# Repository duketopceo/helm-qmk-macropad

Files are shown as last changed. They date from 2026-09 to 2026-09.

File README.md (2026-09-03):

# Helm

Private. Made-to-order USB-C macropad. Developer-first command surface, QMK/Vial second, real Linux (Omarchy/Hyprland) as the wedge Elgato and Logitech skip.

**First working build:** 6 MX keys (2×3) + one clickable aluminum EC11 knob. Hand-soldered. Seeed XIAO RP2040. PETG two-piece, 15° desk wedge. No custom app until it enumerates as HID on macOS, Windows, and Linux.

## Locked spec

| | |
|---|---|
| Layout | 6× MX 2×3 + 1× EC11 click-knob |
| Angle | **15°** wedge, front low, USB at the tall rear. Not Stream Deck Mini's 45° (that's for LCDs) |
| Keys | **PCB-mount / 5-pin** MX. Plate is **1.5 mm** at the clips (Cherry spec; thicker and they do not latch) |
| Knob | **Threaded** EC11 + nut + washer. Body sits on a printed shelf. No snap-in-only encoder |
| MCU | Seeed XIAO RP2040, USB-C rear, wired. Cable zip-tied at the rear wall |
| Firmware v1 | QMK + Vial (`vial.rocks`). Prebuilt: `firmware/handwired_helm_vial.uf2` |
| Case | Dark PETG, 2.4 mm walls, 4× M2 heat-set inserts, 2 alignment pins. No structural snaps |
| Out of v1 | ESP32, RGB, screen, wireless, 5 knobs, companion app, Stripe |

MX cutout 14.0 mm @ 19.05 mm pitch, 0.5 mm corner radii, 1.8 mm holes at ±5.08 mm for the plastic legs. EC11 bushing 7.2 mm. XIAO pocket 21.2×17.7×1.2 mm. Plate ~75×65 mm in the key plane; desk footprint ~75×62 mm. Rear wall ~26 mm tall.

USB-C on the XIAO is reversible (plug either flip). The board only faces rear.

## First-working sequence

1. Flying-lead **one key + one encoder**, flash Vial, confirm HID on all three OSes.
2. Print the 15° shell + 1.5 mm plate.
3. Seat 5-pin MX, nut the encoder, zip-tie the USB cable, solder the other five keys, close with M2.
4. Daily-drive a week. If the knob is only volume, we keep one knob forever.

## Buy list (v1)

See `BOM.md`. Short version: XIAO ×2, **5-pin** Gateron MX 10-pack, **threaded** EC11 + nut + washer + aluminum knob, 6× 1u PBT blanks, M2 inserts + M2×8–10 screws, zip-tie, 26–28 AWG, PETG you already have.

## Competition (why not 5 knobs)

- Stream Deck Mini — 6 keys, 45° LCD stand, still the compact one people love
- Stream Deck + — 8 LCD + 4 dials; 4 knobs is the ceiling
- Logitech MX Creative Console — 9 LCD + **one** big dial
- OpenAI Codex Micro / Work Louder Creator Micro 2 — 13 keys + **one** reasoning dial, $230

Helm's gap: cheap QMK MX + one knob + Linux that actually works. Free 3×3 Arduino STLs (e.g. SNASA on Printables) are the hobby floor, NC-licensed, and not this product.

## Repo layout

```
├── cad/             # Parametric OpenSCAD (edit helm_parameters.scad)
│   ├── helm_parameters.scad
│   ├── helm_plate.scad
│   └── helm_bottom.scad
├── stl/             # Generated plate and bottom
├── firmware/
│   ├── handwired_helm_vial.uf2
│   └── qmk/keyboards/handwired/helm/
├── WIRING.md
└── BOM.md
```

## How to print (Ender V3, PETG)

1. Slice `stl/helm_plate.stl` and `stl/helm_bottom.stl`.
2. **Plate:** flat on the bed, switch-face up. **100% infill, ≥4 walls**, 0.15–0.20 mm layers. No supports. Do not thicken the plate past 1.6 mm or MX clips will not lock.
3. **Bottom:** desk-face on the bed (USB slot in the tall rear wall, bosses up). No supports. 4 walls, 25–30% infill is fine.
4. ~240 °C PETG / 80 °C bed, 45 mm/s outer walls.
5. Rebuild STLs after CAD edits (run from `cad/` so the include resolves):

```bash
cd cad
openscad -o ../stl/helm_plate.stl helm_plate.scad
openscad -o ../stl/helm_bottom.stl helm_bottom.scad
```

6. Heat-set four M2 inserts from the **plate side** of the bosses (~200 °C iron, vertical, no twisting). Alignment pins locate the plate. M2 screws, not snaps.

Hold XIAO **BOOT while plugging USB** to flash. There are no underside button holes.

## How to flash

Fast path: hold BOOT, plug USB, copy `firmware/handwired_helm_vial.uf2` onto the `RPI-RP2` drive.

Rebuild:

1. Clone `vial-kb/vial-qmk` and run `qmk setup` against it.
2. Copy `firmware/qmk/keyboards/handwired/helm/` into `keyboards/handwired/`.
3. `qmk compile -kb handwired/helm -km vial`
4. Same UF2 copy as above.

## Verify HID

- **macOS** — System Settings > Keyboard should list "Helm". The first key emits `KC_MUTE`.
- **Windows** — HID Keyboard, VID `0x484D` PID `0x0001`.
- **Omarchy / Hyprland** — `lsusb` / `dmesg`. Open `vial.rocks`, authorize, test all 6 keys, knob click, and both rotate directions.

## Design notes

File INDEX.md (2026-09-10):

# INDEX.md — Luke Grounding Index

> **Index version:** `v2.0.0`
> **Repo version:** `1.0.0`
> **Last synced:** `2026-09-10T07:20:22.933510+00:00`
> **Schema:** `Path | Version | Last updated | What it is | Why it's here | Depends on`
>
> **This file is auto-generated by `scripts/luke-index-watcher.py`.**
> Hand-maintained `What it is`, `Why it's here`, and `Depends on` values are preserved.

---

## 1. Security & Leak Risk

> [!IMPORTANT]
> Run `python scripts/luke-index-watcher.py` after any non-trivial repo change to keep this index current.
> Never commit live keys, tokens, or PII. See `GUARDRAILS.md` §6 and `SECURITY_GUIDELINES.md`.

---

## 2. Root-level files

| Path | Version | Last updated | What it is | Why it's here | Depends on |
| --- | --- | --- | --- | --- | --- |
| BOM.md | 1.0.0 | 2026-09-03T05:07:35 |  |  |  |
| INDEX.md | 1.0.0 | 1970-01-01T00:00 |  |  |  |
| README.md | 1.0.0 | 2026-09-03T05:07:35 |  |  |  |
| WIRING.md | 1.0.0 | 2026-09-03T05:07:35 |  |  |  |

## 3. `cad/`

| Path | Version | Last updated | What it is | Why it's here | Depends on |
| --- | --- | --- | --- | --- | --- |
| cad/helm_bottom.scad | 1.0.0 | 2026-09-03T04:55:53 |  |  |  |
| cad/helm_parameters.scad | 1.0.0 | 2026-09-03T04:55:53 |  |  |  |
| cad/helm_plate.scad | 1.0.0 | 2026-09-03T04:55:53 |  |  |  |
| cad/preview.png | 1.0.0 | 2026-09-03T04:55:53 |  |  |  |
| cad/preview_bottom.png | 1.0.0 | 2026-09-03T04:55:53 |  |  |  |
| cad/preview_plate.png | 1.0.0 | 2026-09-03T04:55:53 |  |  |  |

## 3. `firmware/`

| Path | Version | Last updated | What it is | Why it's here | Depends on |
| --- | --- | --- | --- | --- | --- |
| firmware/handwired_helm_vial.uf2 | 1.0.0 | 2026-09-03T04:06:47 |  |  |  |
| firmware/qmk/keyboards/handwired/helm/config.h | 1.0.0 | 2026-09-03T04:06:47 |  |  |  |
| firmware/qmk/keyboards/handwired/helm/keyboard.json | 1.0.0 | 2026-09-03T04:06:47 |  |  |  |
| firmware/qmk/keyboards/handwired/helm/keymaps/vial/keymap.c | 1.0.0 | 2026-09-03T04:06:47 |  |  |  |
| firmware/qmk/keyboards/handwired/helm/keymaps/vial/rules.mk | 1.0.0 | 2026-09-03T04:00:24 |  |  |  |
| firmware/qmk/keyboards/handwired/helm/keymaps/vial/vial.json | 1.0.0 | 2026-09-03T04:00:24 |  |  |  |
| firmware/qmk/keyboards/handwired/helm/rules.mk | 1.0.0 | 2026-09-03T04:00:24 |  |  |  |

## 3. `scripts/`

| Path | Version | Last updated | What it is | Why it's here | Depends on |
| --- | --- | --- | --- | --- | --- |
| scripts/luke-index-watcher.py | 1.0.0 | 1970-01-01T00:00 |  |  |  |

## 3. `stl/`

| Path | Version | Last updated | What it is | Why it's here | Depends on |
| --- | --- | --- | --- | --- | --- |
| stl/helm_bottom.stl | 1.0.0 | 2026-09-03T04:55:53 |  |  |  |
| stl/helm_plate.stl | 1.0.0 | 2026-09-03T04:55:53 |  |  |  |

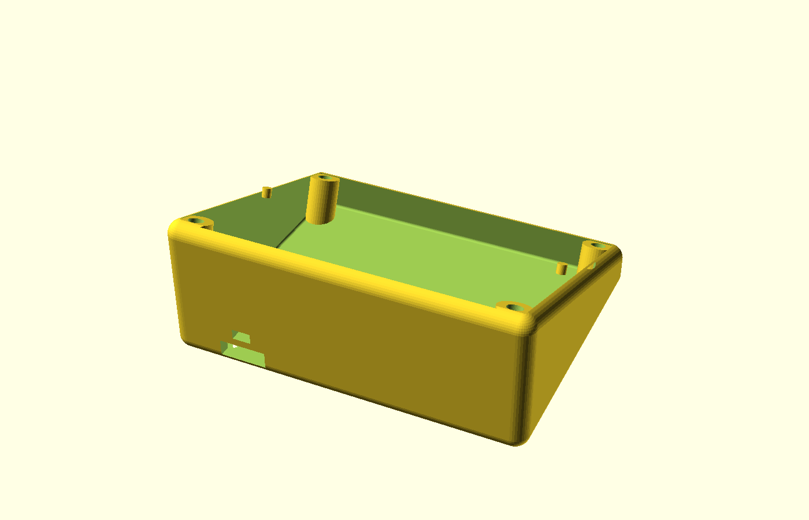
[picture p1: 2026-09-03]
cad/preview_bottom.png

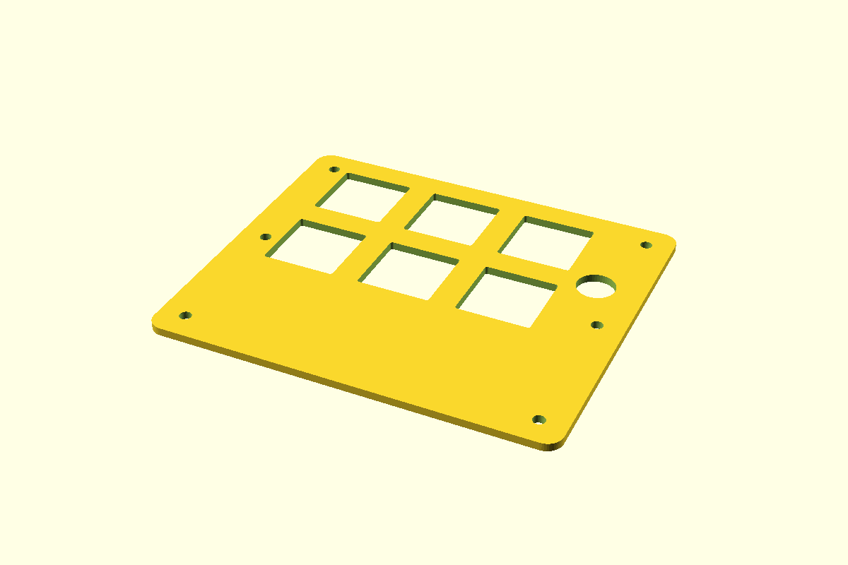
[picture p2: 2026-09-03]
cad/preview_plate.png

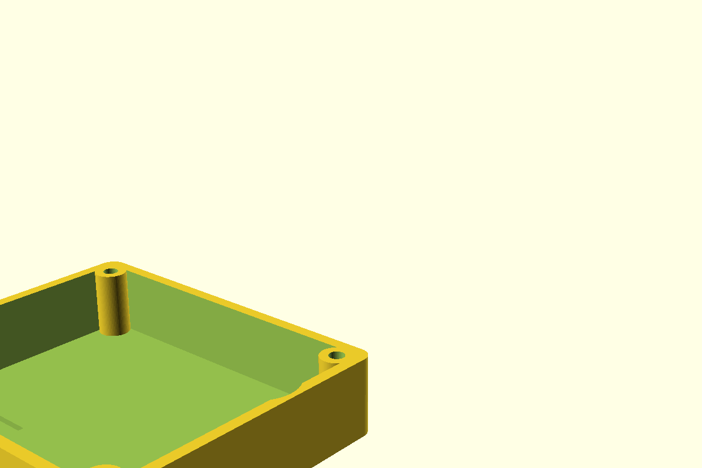
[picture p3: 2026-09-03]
cad/preview.png

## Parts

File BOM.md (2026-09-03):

# Helm v1 BOM

| Item | Qty | Notes |
|---|-----|---|
| Seeed Studio XIAO RP2040 | 2 | One for the build, one spare |
| Gateron (or Cherry) **PCB-mount 5-pin** MX | 6 | Buy a 10-pack. 3-pin plate-only switches skip the anti-rotation pegs |
| EC11 with **threaded bushing + nut + washer**, push switch | 1 | ~7 mm bushing. Skip Alps parts with no collar |
| Aluminum knob | 1 | 6 mm D-shaft |
| 1u PBT blank keycaps | 6 | MX stem |
| M2 brass heat-set inserts | 4 | Length 3–4 mm, OD ~3.5 mm. Iron ~200 °C in PETG |
| M2 pan-head screws | 4 | **8–10 mm** (insert + 1.5 mm plate) |
| Small nylon zip-tie | 1 | Strain relief through the rear-wall slot |
| 26–28 AWG stranded wire | ~2 m | Direct-pin flying leads |
| Dark PETG | ~50 g | Plate + bottom |
| Rubber feet | 4 | Optional, 10 mm, sit in the recesses |

## Optional but recommended

- USB-C **data** cable (charge-only will not enumerate). Plug is reversible.
- Flux and no-clean solder for the XIAO castellated pads
- Flush cutters for EC11 legs
- Spare M2 inserts in case one spins

Do not substitute a snap-in-only encoder or a uniform plate thicker than 1.6 mm.

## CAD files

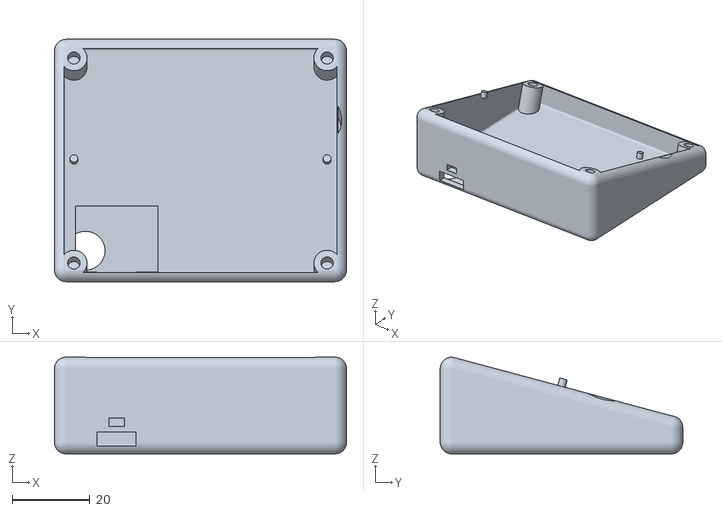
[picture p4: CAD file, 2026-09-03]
stl/helm_bottom.stl
75.1 x 62.4 x 24.9

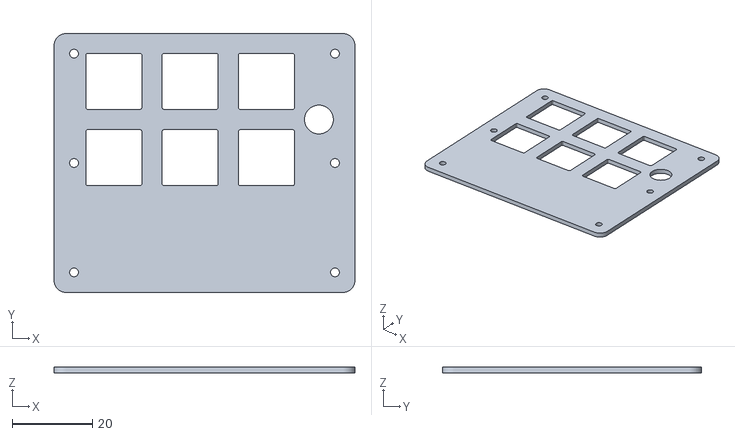
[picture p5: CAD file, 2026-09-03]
stl/helm_plate.stl
75.1 x 64.6 x 1.50

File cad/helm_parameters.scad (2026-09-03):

// Helm v1 — 6 MX (2x3) + 1 EC11 + XIAO RP2040
// Units: mm.
// y=0 rear (USB, tall). y=plate_depth front (toward the user, short).
// Key plane is desk_angle degrees off the desk. Front low, rear high.

// --- MX ---
mx_pitch     = 19.05;
mx_cutout    = 14.0;
mx_corner_r  = 0.5;   // stop PETG cracks at square hole corners
mx_peg_d      = 1.8;   // 5-pin plastic legs, KiCad ±5.08 mm from center
mx_peg_x      = 5.08;

// --- EC11 (buy the threaded-bushing version + nut + washer) ---
ec11_bushing = 7.2;
ec11_body    = 14.0;
bridge       = 2.5;

// --- case ---
wall             = 2.4;
corner_r         = 3.0;
plate_thickness  = 1.5;  // Cherry clip land; do not go thicker
case_floor       = 2.0;
front_h          = 9.0;   // wall height at the front lip (desk to plate underside)
desk_angle       = 15;
bay_gap          = 4.0;
align_pin_d      = 2.0;
align_pin_h      = 2.0;

// --- XIAO RP2040 ---
xiao_w            = 21.2;
xiao_d            = 17.7;
xiao_pocket_depth = 1.2;
usb_w             = 10.0;
usb_h             = 3.6;
usb_z             = case_floor;
zip_w             = 4.0;  // strain-relief zip-tie slot in the rear wall
zip_h             = 2.2;

// --- M2 heat-set ---
m2_through     = 2.2;
m2_insert      = 3.2;
m2_insert_h    = 4.5;
boss_d         = 6.8;
screw_inset    = 5.0;

// --- rubber feet ---
foot_d = 10.0;
foot_h = 0.8;
foot_inset = 8.0;

// --- derived layout (in the KEY / plate plane) ---
grid_x0 = wall + 3.0 + 0.5 * mx_pitch;
grid_y0 = wall + xiao_d + bay_gap + 0.5 * mx_pitch;

key_centers_x = [grid_x0, grid_x0 + mx_pitch, grid_x0 + 2 * mx_pitch];
key_centers_y = [grid_y0, grid_y0 + mx_pitch];

encoder_x = key_centers_x[2] + mx_cutout / 2 + bridge + ec11_bushing / 2;
encoder_y = (key_centers_y[0] + key_centers_y[1]) / 2;

plate_width = encoder_x + ec11_bushing / 2 + wall + 3.0;
plate_depth = key_centers_y[1] + 0.5 * mx_pitch + wall;

desk_depth = plate_depth * cos(desk_angle);
rear_h     = front_h + desk_depth * tan(desk_angle);

xiao_x = wall + 3.0;
xiao_y = wall;

screw_positions = [
    [screw_inset, screw_inset],
    [plate_width - screw_inset, screw_inset],
    [screw_inset, plate_depth - screw_inset],
    [plate_width - screw_inset, plate_depth - screw_inset]
];

// alignment pins sit mid-left and mid-right, in the key plane
align_positions = [
    [screw_inset, plate_depth / 2],
    [plate_width - screw_inset, plate_depth / 2]
];

foot_positions = [
    [foot_inset, foot_inset],
    [plate_width - foot_inset, foot_inset],
    [foot_inset, desk_depth - foot_inset],
    [plate_width - foot_inset, desk_depth - foot_inset]
];

function z_top(y_desk) = front_h + (desk_depth - y_desk) * tan(desk_angle);

module plate_to_world() {
    // plate coords: z up from plate underside, y from rear to front along the plate
    translate([0, 0, rear_h])
        rotate([-desk_angle, 0, 0])
            children();
}

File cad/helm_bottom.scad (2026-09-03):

include <helm_parameters.scad>
$fn = 40;

module wedge_solid(xy_inset) {
    r = max(0.4, corner_r - xy_inset);
    w = plate_width - 2 * xy_inset;
    d = desk_depth - 2 * xy_inset;
    hull() {
        for (x = [r, w - r], y = [r, d - r]) {
            translate([xy_inset + x, xy_inset + y, r])
                sphere(r = r);
            zt = z_top(xy_inset + y) - r;
            translate([xy_inset + x, xy_inset + y, zt])
                sphere(r = r);
        }
    }
}

module helm_bottom() {
    difference() {
        union() {
            difference() {
                wedge_solid(0);
                translate([0, 0, case_floor])
                    wedge_solid(wall);
            }

            // bosses stay inside the wedge
            intersection() {
                wedge_solid(0);
                union() {
                    for (p = screw_positions)
                        plate_to_world()
                            translate([p[0], p[1], -12])
                                cylinder(h = 12, d = boss_d);
                }
            }

            for (p = align_positions)
                plate_to_world()
                    translate([p[0], p[1], 0])
                        cylinder(h = align_pin_h, d = align_pin_d);
        }

        for (p = screw_positions)
            plate_to_world()
                translate([p[0], p[1], -m2_insert_h])
                    cylinder(h = m2_insert_h + 0.3, d = m2_insert);

        translate([xiao_x, xiao_y, case_floor - xiao_pocket_depth])
            cube([xiao_w, xiao_d * cos(desk_angle), xiao_pocket_depth + 0.2]);

        translate([xiao_x + xiao_w / 2 - usb_w / 2, -1, usb_z])
            cube([usb_w, wall + 2, usb_h]);

        translate([xiao_x + xiao_w / 2 - zip_w / 2, -1, usb_z + usb_h + 1.5])
            cube([zip_w, wall + 2, zip_h]);

        intersection() {
            translate([0, 0, case_floor + 0.5])
                cube([plate_width, desk_depth, rear_h]);
            plate_to_world()
                translate([encoder_x, encoder_y, -25])
                    cylinder(h = 25, d = ec11_body + 1.5);
        }

        for (p = foot_positions)
            translate([p[0], p[1], -0.01])
                cylinder(h = foot_h + 0.01, d = foot_d);
    }
}

helm_bottom();

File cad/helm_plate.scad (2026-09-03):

include <helm_parameters.scad>
$fn = 48;

module rounded_rect(w, d, r) {
    hull() {
        for (x = [r, w - r], y = [r, d - r])
            translate([x, y, 0]) circle(r = r);
    }
}

module mx_hole_2d() {
    offset(r = mx_corner_r)
        square(mx_cutout - 2 * mx_corner_r, center = true);
}

module helm_plate() {
    difference() {
        linear_extrude(height = plate_thickness)
            rounded_rect(plate_width, plate_depth, corner_r);

        for (x = key_centers_x, y = key_centers_y) {
            translate([x, y, -0.1])
                linear_extrude(height = plate_thickness + 0.2)
                    mx_hole_2d();
            // 5-pin plastic legs
            for (dx = [-mx_peg_x, mx_peg_x])
                translate([x + dx, y, -1])
                    cylinder(h = plate_thickness + 2, d = mx_peg_d);
        }

        translate([encoder_x, encoder_y, -1])
            cylinder(h = plate_thickness + 2, d = ec11_bushing);

        for (p = screw_positions)
            translate([p[0], p[1], -1])
                cylinder(h = plate_thickness + 2, d = m2_through);

        for (p = align_positions)
            translate([p[0], p[1], -1])
                cylinder(h = plate_thickness + 2, d = align_pin_d + 0.2);
    }
}

helm_plate();

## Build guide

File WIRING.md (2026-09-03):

# Helm wiring

Direct-pin: each switch terminal goes to one GPIO on the Seeed XIAO RP2040; the other terminal goes to GND. No matrix, no diodes. Pins match `firmware/qmk/keyboards/handwired/helm/keyboard.json`.

Looking at the plate, USB at the rear (away from you):

## Pin map

| Helm function | XIAO silk | RP2040 GPIO |
|---|---|---|
| Key 1 top left | D0 | GP26 |
| Key 2 top middle | D1 | GP27 |
| Key 3 top right | D2 | GP28 |
| Key 4 bottom left | D3 | GP29 |
| Key 5 bottom middle | D4 | GP6 |
| Key 6 bottom right | D5 | GP7 |
| EC11 click | D8 | GP2 |
| EC11 A | D9 | GP4 |
| EC11 B | D10 | GP3 |
| Ground rail | GND | — |

## Flying-lead first (1 key + 1 encoder)

1. Snap a **5-pin** MX into the plate (plastic legs into the 1.8 mm holes). Wire one terminal to **D0 (GP26)**, the other to **GND**.
2. Seat the EC11 from below. **Nut + washer on top of the plate.** Body rests on the printed shelf. A to **D9 (GP4)**, B to **D10 (GP3)**, click to **D8 (GP2)** and GND.
3. Drop the XIAO into the rear floor pocket, USB-C through the rear wall. Cable plugs either flip. **Zip-tie the cable in the slot above the USB hole** before you yank-test it.
4. Flash (`firmware/handwired_helm_vial.uf2` or rebuild). `vial.rocks`: one key, click, both rotate directions.

## Remaining 5 keys

Same as key 1: one terminal to D1 / D2 / D3 / D4 / D5, other to the GND rail. Tin the XIAO GND pad and fan a short rail. QMK enables RP2040 pull-ups; no extra resistors.

## Do not

- Mount the encoder on the 7.2 mm hole with no nut. Knob torque will crack the plate (Bento's failure mode).
- Skip the zip-tie. A USB yank pulls the XIAO out of the pocket.
- Rely on snaps to close the case. M2 inserts only.
- Expect underside BOOT holes. Hold **BOOT while plugging in**.

Keep D+/D- pads clear. Trim EC11 legs after soldering so the body clears the shelf.

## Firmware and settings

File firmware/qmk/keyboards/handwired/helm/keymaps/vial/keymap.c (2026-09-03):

#include QMK_KEYBOARD_H

const uint16_t PROGMEM keymaps[][MATRIX_ROWS][MATRIX_COLS] = {
    [0] = LAYOUT(
        KC_MUTE, KC_VOLU, KC_VOLD,
        KC_MPLY, KC_MNXT, KC_MPRV, KC_ENT
    ),
    [1] = LAYOUT(
        KC_1, KC_2, KC_3,
        KC_4, KC_5, KC_6, KC_0
    ),
    [2] = LAYOUT(
        KC_F1, KC_F2, KC_F3,
        KC_F4, KC_F5, KC_F6, KC_F7
    ),
    [3] = LAYOUT(
        KC_NO, KC_NO, KC_NO,
        KC_NO, KC_NO, KC_NO, KC_NO
    )
};

#if defined(ENCODER_MAP_ENABLE)
const uint16_t PROGMEM encoder_map[][NUM_ENCODERS][2] = {
    [0] = { ENCODER_CCW_CW(KC_VOLD, KC_VOLU) },
    [1] = { ENCODER_CCW_CW(KC_NO,   KC_NO)   },
    [2] = { ENCODER_CCW_CW(KC_NO,   KC_NO)   },
    [3] = { ENCODER_CCW_CW(KC_NO,   KC_NO)   }
};
#endif

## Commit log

2026-09-03 Add Helm v1 build artifacts: OpenSCAD, STLs, QMK/Vial firmware, wiring, and BOM
    - Parametric OpenSCAD plate + bottom from MX / EC11 / XIAO footprints
    - Generated STLs in stl/
    - QMK/Vial keymap for 6 MX keys + clickable EC11 knob
    - WIRING.md with XIAO RP2040 pin map and flying-lead sequence
    - BOM.md matching the locked buy list
    - README expanded with print, flash, and HID verification instructions
    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
    [helm_bottom.scad, helm_bottom.stl, helm_parameters.scad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]
2026-09-03 Add 15° wedge case and 1.5 mm MX plate.
    Parametric OpenSCAD now tilts the 6+1 toward the user, uses Cherry clip-land thickness with 5-pin peg holes, and keeps M2 inserts plus USB strain relief. Regenerated STLs for the Ender V3.
    [helm_bottom.scad, helm_bottom.stl, helm_parameters.scad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]
2026-09-03 Document the 15° wedge, 1.5 mm 5-pin plate, and strain relief.
    README, BOM, and WIRING now match the printed case: Cherry clip-land thickness, threaded EC11, M2 inserts, zip-tied USB-C, and the prebuilt UF2 flash path.
2026-09-10 chore: add auto-generated grounding index and watcher
